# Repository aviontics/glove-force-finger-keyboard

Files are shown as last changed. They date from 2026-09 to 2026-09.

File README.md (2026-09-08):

# Sentient Glove

**A hands-free hotkey glove.** Tap your fingertips to fire keyboard keys on your PC — push-to-talk, Enter, macros, anything — with no Bluetooth pairing, sub-10 ms latency and long range.

Built by [Sentient Robotics](https://sentientrobotics.example) on the ESP32-S3.

---

## How it works

```
 ┌──────────────┐   2.4 GHz ESP-NOW    ┌──────────────┐   USB HID    ┌──────┐
 │  GLOVE       │ ───────────────────▶ │  DONGLE      │ ───────────▶ │  PC  │
 │  ESP32-S3    │   long-range mode    │  ESP32-S3    │  (keyboard)  │      │
 │  3 × FSR     │                      │              │ ◀──────────▶ │      │
 └──────────────┘                      └──────────────┘  USB serial  └──────┘
                                                          (config app)
```

- The **glove** carries an ESP32-S3 and three thin-film force sensors on the fingertips. It detects taps, double-taps and long presses and sends them by radio.
- The **dongle** is a second ESP32-S3 plugged into the PC. It appears as a standard wired USB keyboard and turns each gesture into a keystroke. The key mapping lives on the dongle in flash, so remapping never touches the glove.
- The **Sentient Glove Control** desktop app talks to the dongle over USB serial to configure key mappings and show live telemetry, including a range radar.

Because the dongle is a plain USB keyboard, it works on any machine with no drivers and no pairing.

---

## Repository layout

| Path | What it is |
|---|---|
| `firmware/glove_sender_v2.ino` | Glove firmware: sensor reading, gesture engine, heartbeat, LED |
| `firmware/dongle_hid_v4.ino` | Dongle firmware: ESP-NOW receiver, USB HID keyboard, keymap storage, serial protocol |
| `app/sentient_glove_control.py` | PyQt6 desktop configurator |
| `hardware/` | Enclosure CAD (Fusion 360) and bill of materials |

---

## Hardware

### Bill of materials (per glove)

| Qty | Part | Notes |
|---|---|---|
| 1 | Seeed XIAO ESP32S3 Plus | Glove controller. Built-in LiPo charging. |
| 1 | ESP32-S3 board with native USB (XIAO ESP32S3 or S3 mini dev board) | Dongle |
| 3 | Thin-film force-sensitive resistor (FSR 400 type, 20 g–10 kg) | One per fingertip |
| 1 | 3.7 V LiPo, ~500 mAh, JST-PH | Glove power |
| 1 | Mini slide switch | Battery on/off |
| 1 | Thin sports/cycling glove | Wearable base |
| — | 30 AWG silicone wire, heat-shrink, adhesive | Harness |
| — | 3D-printed enclosure (see `hardware/`) | Two-tier case: battery below, board above |

No resistors are required: the sensors are read in **digital mode** using the ESP32's internal pull-ups.

### Wiring the glove

Each sensor connects between **its GPIO and GND**. Nothing connects to 3V3.

| Finger | GPIO | XIAO pin |
|---|---|---|
| 1 | GPIO1 | A0 / D0 |
| 2 | GPIO5 | D4 |
| 3 | GPIO3 | A2 / D2 |

Both GND legs from all three sensors can share one wire back to the board's GND pin.

> **Handling FSRs:** never solder directly to the sensor's film tail — the printed traces delaminate with heat. Use crimp connectors or a slide-on female header.

> **GPIO3 is a strapping pin.** Don't hold finger 3 pressed while powering on or resetting the glove.

Battery: solder the LiPo to the BAT+ / BAT− pads on the underside of the XIAO, with the slide switch in the BAT+ line. Charging happens automatically over the board's USB-C.

### Power-on indicator

The XIAO's user LED (GPIO21) flashes briefly every two seconds while the glove is running. Flip the switch on → LED flashes; off → dark. The orange LED next to it is the charger and lights on its own while charging.

---

## Firmware

Both boards are programmed from the Arduino IDE with the **esp32** board package (3.x) installed via Boards Manager. Use **Arduino IDE 2.x** — on Ubuntu, install it from arduino.cc, not the snap, and add yourself to the `dialout` group.

### Glove — `glove_sender_v2.ino`

Board: your XIAO ESP32S3 / ESP32S3 Dev Module. Default USB settings. Flash normally.

Adding sensors later is a two-line edit at the top of the file:

```cpp
const uint8_t NUM = 3;
const uint8_t fsrPins[NUM]     = {1, 5, 3};
const bool    dtapEnabled[NUM] = {true, true, true};
```

### Dongle — `dongle_hid_v4.ino`

Board settings that matter:

| Setting | Value |
|---|---|
| USB Mode | **USB-OTG (TinyUSB)** |
| USB CDC On Boot | **Enabled** |

**Flashing a board that is already running dongle firmware:** the auto-reset doesn't work in OTG mode, so:

1. Hold **BOOT**, tap **RESET**, release **BOOT** — the board enters download mode and its serial port appears.
2. Upload.
3. Press **RESET** once more to run the new firmware. (Forgetting this leaves the board sitting in the bootloader: no keyboard, and a serial port that never answers.)

After flashing, the dongle shows up as a USB keyboard *and* a USB serial port at the same time.

Both boards are hard-coded to radio channel 6 in long-range mode and must match. They pair automatically — no MAC addresses to enter.

---

## Using the glove

### Gestures

Every finger supports three independent gestures. Each is mapped to a **binding**: any combination of Ctrl / Shift / Alt / Win plus one key.

| Gesture | How | Default bindings (F1 / F2 / F3) |
|---|---|---|
| **Tap** | Press and release within 400 ms | `a` / `Ctrl+Alt+J` / `Enter` |
| **Double tap** | Two taps within 250 ms | `A` / `B` / `C` |
| **Long press** | Hold longer than 400 ms | `Ctrl+Alt+R` / `F14` / `F15` |

Long press behaves like holding real keys: the whole combination goes **down** at the 400 ms mark and comes **up** when you let go. This is how push-to-talk works — e.g. finger 1 long press = `Ctrl+Alt+R` held for as long as the finger is down. Modifiers are reference-counted on the dongle, so tapping another finger's combo while a PTT combo is held never releases the shared modifiers.

F13–F24 are the recommended PTT keys: no application uses them by default, so they never collide with anything. Bind them in Discord, TeamSpeak or your game.

**Latency note:** on a finger with double-tap enabled, a single tap fires ~250 ms after release (the glove waits to see if a second tap is coming). Fingers with double-tap disabled fire instantly. Set `dtapEnabled` per finger accordingly.

### Setup mode (remap without the app)

Hold any sensor for **10 seconds**. The glove requests setup for that finger; if the desktop app is connected, a dialog opens to assign its three keys. Release the sensor, choose the keys, done. Mappings are saved to the dongle's flash immediately and survive power cycles.

> During the 10-second hold the long-press key is held down until the 10 s mark, then released. Click into the app or a harmless window first.

Timing constants (`LONG_MS`, `DOUBLE_GAP_MS`, `SETUP_MS`) are at the top of the glove firmware if you want to tune the feel.

---

## Sentient Glove Control (desktop app)

Sentient Glove Control

### Install

```bash
pip install PyQt6 pyserial
python app/sentient_glove_control.py
```

Runs on Windows, macOS and Linux. On Linux you need read/write access to the dongle's serial port (`dialout` group on Ubuntu).

### Interface

**Dongle Link** — click **SCAN**, choose the dongle's port, click **CONNECT**. The status indicator turns green (`GLOVE ONLINE`) as soon as heartbeats arrive from the glove. `SERIAL ONLY — NO GLOVE` means the dongle is connected but the glove is off or out of range.

**Key Mapping** — a grid of finger × gesture. Each cell is a key picker with **Ctrl / Shift / Alt / Win** tickboxes beneath it: choose a named key from the dropdown (Enter, Backspace, Tab, Esc, Space, Delete, Home/End, Page Up/Down, arrows, F1–F24) or type a single character, then tick the modifiers you want combined with it. Leave the key blank to unassign that gesture (or blank with modifiers ticked for a modifier-only binding).
- **READ FROM DEVICE** pulls the current map from the dongle.
- **APPLY ALL** writes every cell to the dongle's flash.

**Telemetry** — live log of every gesture received (`finger 2: DOUBLE TAP`), setup requests and command results. Use it to verify sensors and timing.

**Glove Range** — a sweep radar showing link strength (RSSI). The blip drifts outward as signal weakens; the centre shows an estimated distance. Click **CALIBRATE @ 1 m** with the glove one metre from the dongle to anchor the estimate to your hardware. Distance derived from signal strength is indicative only — it's a link-health indicator, not a tape measure. `NO LINK` appears if no heartbeat arrives for 2 seconds.

### Serial protocol

The app is optional — anything that speaks 115200-baud serial can configure the dongle.

| Direction | Message | Meaning |
|---|---|---|
| PC → dongle | `GET` | Request the keymap |
| PC → dongle | `SET,f,slot,mods,code` | Set finger `f` (0–5), slot `t`/`d`/`l` (tap/double/long): `mods` bitmask (1 Ctrl, 2 Shift, 4 Alt, 8 Win) + HID keycode `code` (0–255; 0 = none) |
| dongle → PC | `READY` | Booted |
| dongle → PC | `MAP,f,tm,tk,dm,dk,lm,lk` | One line per finger: mods,key for tap, double-tap, long press |
| dongle → PC | `EV,f,code` | Gesture received: 1 tap, 2 double, 3 long start, 4 long end, 5 setup |
| dongle → PC | `HB,rssi` | Heartbeat with link RSSI in dBm (every ~400 ms) |
| dongle → PC | `SETUP,f` | Glove requested setup for finger `f` |
| dongle → PC | `OK` / `ERR` | Command result |

Keycodes follow the Arduino keyboard convention: printable characters are their ASCII value; special keys are `0x80`+ (Enter `176`, Backspace `178`, F13 `240`, …).

---

## Troubleshooting

| Symptom | Likely cause | Fix |
|---|---|---|
| Nothing types, app opens the port but gets no response | Dongle stuck in bootloader after flashing | Press **RESET** on the dongle |
| Serial port disappears after flashing the dongle | Expected — it's now a keyboard | Enable *USB CDC On Boot*, and use BOOT+RESET to reflash |
| App connects but `NO LINK` | Glove off, out of range, or channel/LR mismatch | Check switch/LED, bring closer, confirm both firmwares use channel 6 + LR |
| A tap fires on two fingers at once | Sensor wires bridged or wrong pins | Continuity-check between finger signal wires; verify GPIO assignments |
| Taps trigger too easily / when gripping things | Thin-film sensors are sensitive | Raise `DEBOUNCE_MS`, mount sensors flat (not under tension), or use firmer press |
| Slow single taps | Double-tap wait | Set `dtapEnabled` to `false` for that finger |
| Glove won't reset/boot | Finger 3 held during power-up | Release finger 3 (GPIO3 is a strapping pin) |

---

## Roadmap

- Battery percentage reported to the app (spare byte in the heartbeat)
- Multi-key macros / sequences per gesture
- Media keys (volume, play/pause)
- Per-finger settings in the app (double-tap enable, timing)

---

## License

MIT — see `LICENSE`.

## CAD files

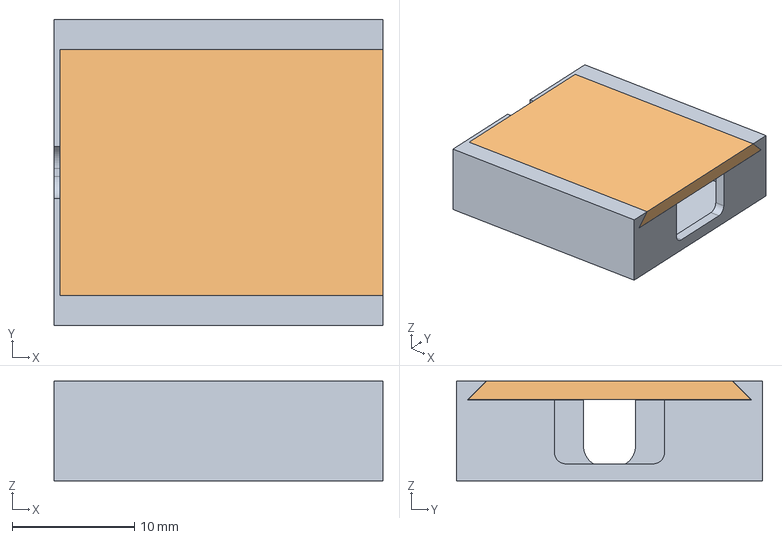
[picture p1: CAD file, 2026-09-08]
hardware/glovecase-dongle-case.step
26.9 x 25.0 x 8.14 mm

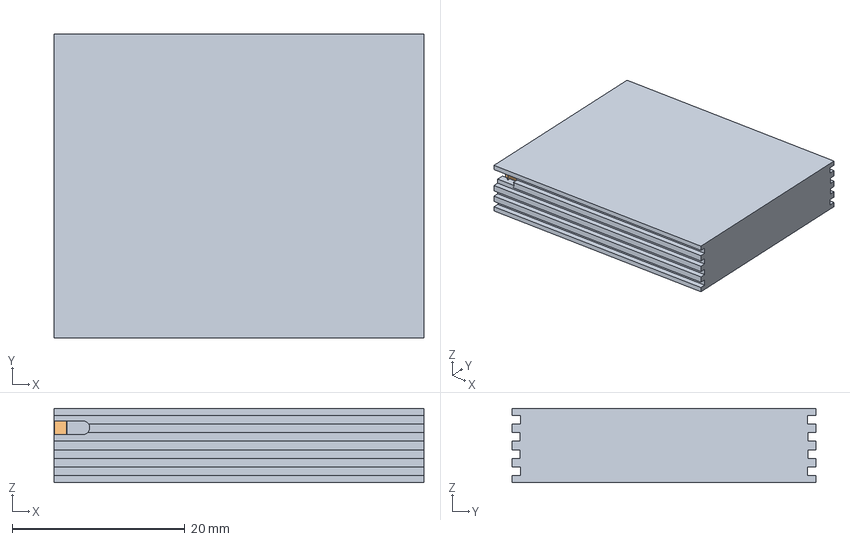
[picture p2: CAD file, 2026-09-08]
hardware/glovecase-battery-case.step
42.9 x 35.3 x 8.59 mm

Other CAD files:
hardware/glovecase-donlge-case-and-battery-case.f3d

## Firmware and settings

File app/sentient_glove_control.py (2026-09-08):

#!/usr/bin/env python3
"""
SENTIENT GLOVE CONTROL
Desktop configurator for the Sentient Robotics hands-free hotkey glove.

Requires:  pip install PyQt6 pyserial
Firmware:  dongle_hid_v2.ino on the dongle, glove_sender_v2.ino on the glove.
Run:       python sentient_glove_control.py
"""

import math
import sys
import time

import serial
from serial.tools import list_ports
from PyQt6 import QtCore, QtGui, QtWidgets

FINGERS = 3          # rows shown in the mapper (firmware supports up to 6)
BAUD = 115200
EV_NAMES = {1: "TAP", 2: "DOUBLE TAP", 3: "LONG PRESS \u25bc", 4: "LONG PRESS \u25b2", 5: "SETUP REQUEST"}
SLOTS = [("t", "Tap"), ("d", "Double tap"), ("l", "Long press")]

# HID keycodes as used by the ESP32 USBHIDKeyboard library (Arduino Keyboard convention).
# Printable keys are their ASCII value; specials live at 0x80+. 0 = unassigned.
SPECIAL_KEYS = [
    ("Enter", 0xB0), ("Backspace", 0xB2), ("Tab", 0xB3), ("Esc", 0xB1), ("Space", 0x20),
    ("Delete", 0xD4), ("Insert", 0xD1), ("Home", 0xD2), ("End", 0xD5),
    ("Page Up", 0xD3), ("Page Down", 0xD6),
    ("Up", 0xDA), ("Down", 0xD9), ("Left", 0xD8), ("Right", 0xD7),
    ("Left Ctrl", 0x80), ("Left Shift", 0x81), ("Left Alt", 0x82), ("Left GUI/Win", 0x83),
    ("Right Ctrl", 0x84), ("Right Shift", 0x85), ("Right Alt", 0x86), ("Right GUI/Win", 0x87),
    ("Caps Lock", 0xC1), ("Print Screen", 0xCE), ("Scroll Lock", 0xCF), ("Pause", 0xD0),
] + [(f"F{n}", 0xC2 + n - 1) for n in range(1, 13)] \
  + [(f"F{n}", 0xF0 + n - 13) for n in range(13, 25)]
NAME_TO_CODE = {name.lower(): code for name, code in SPECIAL_KEYS}
CODE_TO_NAME = {code: name for name, code in SPECIAL_KEYS}


def code_to_label(code: int) -> str:
    if code == 0:
        return ""
    if code in CODE_TO_NAME:
        return CODE_TO_NAME[code]
    if 33 <= code <= 126:
        return chr(code)
    return f"#{code}"


def label_to_code(text: str):
    """Returns a keycode, 0 for blank/none, or None if unrecognised."""
    t = text.strip()
    if t == "" or t.lower() in ("none", "-", "--"):
        return 0
    if t.lower() in NAME_TO_CODE:
        return NAME_TO_CODE[t.lower()]
    if len(t) == 1 and 33 <= ord(t) <= 126:
        return ord(t)
    if t.startswith("#") and t[1:].isdigit() and 0 <= int(t[1:]) <= 255:
        return int(t[1:])
    return None


class KeyPicker(QtWidgets.QComboBox):
    """Editable combo: pick a named special key, or type a single character."""

    def __init__(self):
        super().__init__()
        self.setEditable(True)
        self.setInsertPolicy(QtWidgets.QComboBox.InsertPolicy.NoInsert)
        self.addItem("")
        for name, _ in SPECIAL_KEYS:
            self.addItem(name)
        self.setFixedWidth(112)
        self.lineEdit().setObjectName("keycap")
        self.setToolTip("Type one character, or choose a special key")

    def set_code(self, code: int):
        self.setCurrentText(code_to_label(code))

    def code(self):
        return label_to_code(self.currentText())


MODS = [("Ctrl", 1), ("Shift", 2), ("Alt", 4), ("Win", 8)]


class KeyCell(QtWidgets.QWidget):
    """One gesture binding: modifier tickboxes + key picker."""

    def __init__(self):
        super().__init__()
        lay = QtWidgets.QVBoxLayout(self)
        lay.setContentsMargins(0, 0, 0, 0)
        lay.setSpacing(3)
        self.picker = KeyPicker()
        lay.addWidget(self.picker, 0, QtCore.Qt.AlignmentFlag.AlignHCenter)
        row = QtWidgets.QHBoxLayout()
        row.setSpacing(6)
        self.boxes = {}
        for name, bit in MODS:
            cb = QtWidgets.QCheckBox(name)
            self.boxes[bit] = cb
            row.addWidget(cb)
        lay.addLayout(row)

    def set_binding(self, mods: int, code: int):
        self.picker.set_code(code)
        for bit, cb in self.boxes.items():
            cb.setChecked(bool(mods & bit))

    def binding(self):
        """(mods, code) or None if the key text is unrecognised."""
        code = self.picker.code()
        if code is None:
            return None
        mods = sum(bit for bit, cb in self.boxes.items() if cb.isChecked())
        return mods, code

ACCENT = "#00e5ff"
ACCENT2 = "#1de9b6"
WARN = "#ff5370"
BG = "#070c11"
PANEL = "#0d151d"
TEXT = "#cfe8e6"

QSS = f"""
* {{ font-family: 'Segoe UI', 'DejaVu Sans', sans-serif; }}
QMainWindow, QDialog {{ background: {BG}; }}
QWidget {{ color: {TEXT}; font-size: 13px; }}
QGroupBox {{
    background: {PANEL};
    border: 1px solid #16323d;
    border-radius: 10px;
    margin-top: 14px;
    padding: 10px 8px 8px 8px;
}}
QGroupBox::title {{
    subcontrol-origin: margin; left: 14px; padding: 0 6px;
    color: {ACCENT}; letter-spacing: 3px; font-size: 11px; font-weight: 600;
}}
QPushButton {{
    background: #0f2530; color: {ACCENT};
    border: 1px solid #1a4a5a; border-radius: 6px;
    padding: 6px 14px; letter-spacing: 1px;
}}
QPushButton:hover {{ background: #143544; border-color: {ACCENT}; }}
QPushButton:pressed {{ background: #0a1c26; }}
QPushButton:disabled {{ color: #3a5560; border-color: #14303a; }}
QPushButton#danger {{ color: {WARN}; border-color: #5a1a2a; }}
QComboBox, QLineEdit {{
    background: #091018; border: 1px solid #1a4a5a; border-radius: 6px;
    padding: 5px 8px; color: {TEXT}; selection-background-color: #145a6e;
}}
QLineEdit:focus, QComboBox:focus {{ border-color: {ACCENT}; }}
QLineEdit#keycap {{
    font-family: 'Consolas', 'DejaVu Sans Mono', monospace;
    font-size: 14px; font-weight: 700; color: {ACCENT2};
    qproperty-alignment: AlignCenter;
    border: none; background: transparent;
}}
QCheckBox {{ color: #6f9aa6; font-size: 10px; letter-spacing: 1px; spacing: 3px; }}
QCheckBox::indicator {{
    width: 11px; height: 11px; border: 1px solid #1a4a5a; border-radius: 3px; background: #091018;
}}
QCheckBox::indicator:checked {{ background: {ACCENT}; border-color: {ACCENT}; }}
QComboBox QAbstractItemView {{
    background: #091018; color: {TEXT}; selection-background-color: #145a6e;
    border: 1px solid #1a4a5a;
}}
QPlainTextEdit {{
    background: #050a0f; border: 1px solid #16323d; border-radius: 8px;
    font-family: 'Consolas', 'DejaVu Sans Mono', monospace; font-size: 12px;
    color: #8fd8c8;
}}
QLabel#title {{
    color: {ACCENT}; font-size: 22px; font-weight: 300; letter-spacing: 8px;
}}
QLabel#subtitle {{ color: #4d7a86; font-size: 10px; letter-spacing: 4px; }}
QLabel#status_ok {{ color: {ACCENT2}; letter-spacing: 2px; }}
QLabel#status_bad {{ color: {WARN}; letter-spacing: 2px; }}
QLabel#colhead {{ color: #4d7a86; font-size: 10px; letter-spacing: 2px; }}
"""


# ----------------------------------------------------------------------
class SerialWorker(QtCore.QThread):
    """Owns the serial port; emits every incoming line."""
    line = QtCore.pyqtSignal(str)
    closed = QtCore.pyqtSignal(str)

    def __init__(self, port: str):
        super().__init__()
        self._port_name = port
        self._ser = None
        self._run = True
        self._lock = QtCore.QMutex()

    def run(self):
        try:
            self._ser = serial.Serial(self._port_name, BAUD, timeout=0.2)
        except Exception as e:                                    # noqa: BLE001
            self.closed.emit(f"open failed: {e}")
            return
        buf = b""
        while self._run:
            try:
                chunk = self._ser.read(64)
            except Exception as e:                                # noqa: BLE001
                self.closed.emit(f"link lost: {e}")
                break
            if chunk:
                buf += chunk
                while b"\n" in buf:
                    raw, buf = buf.split(b"\n", 1)
                    text = raw.decode(errors="replace").strip()
                    if text:
                        self.line.emit(text)
        try:
            if self._ser and self._ser.is_open:
                self._ser.close()
        except Exception:                                         # noqa: BLE001
            pass

    def send(self, text: str):
        with QtCore.QMutexLocker(self._lock):
            if self._ser and self._ser.is_open:
                try:
                    self._ser.write((text + "\n").encode())
                except Exception:                                 # noqa: BLE001
                    pass

    def stop(self):
        self._run = False
        self.wait(1000)


# ----------------------------------------------------------------------
class RangeRadar(QtWidgets.QWidget):
    """Futuristic sweep radar showing link RSSI and an estimated range."""

    def __init__(self):
        super().__init__()
        self.setMinimumSize(260, 260)
        self.rssi = None          # smoothed dBm
        self.linked = False
        self.dist = None          # metres, estimated
        self._sweep = 0.0
        timer = QtCore.QTimer(self)
        timer.timeout.connect(self._tick)
        timer.start(33)

    def _tick(self):
        self._sweep = (self._sweep + 2.4) % 360.0
        self.update()

    def set_link(self, rssi, dist, linked):
        self.rssi, self.dist, self.linked = rssi, dist, linked

    def paintEvent(self, _ev):
        p = QtGui.QPainter(self)
        p.setRenderHint(QtGui.QPainter.RenderHint.Antialiasing)
        w, h = self.width(), self.height()
        cx, cy = w / 2, h / 2
        r = min(w, h) / 2 - 12

        p.fillRect(self.rect(), QtGui.QColor(BG))

        grid = QtGui.QPen(QtGui.QColor(20, 60, 72), 1)
        p.setPen(grid)
        for frac in (1.0, 0.72, 0.45, 0.2):
            p.drawEllipse(QtCore.QPointF(cx, cy), r * frac, r * frac)
        p.drawLine(QtCore.QPointF(cx - r, cy), QtCore.QPointF(cx + r, cy))
        p.drawLine(QtCore.QPointF(cx, cy - r), QtCore.QPointF(cx, cy + r))

        if self.linked:
            # sweep wedge
            grad = QtGui.QConicalGradient(cx, cy, -self._sweep)
            grad.setColorAt(0.0, QtGui.QColor(0, 229, 255, 120))
            grad.setColorAt(0.12, QtGui.QColor(0, 229, 255, 0))
            grad.setColorAt(1.0, QtGui.QColor(0, 229, 255, 0))
            p.setBrush(QtGui.QBrush(grad))
            p.setPen(QtCore.Qt.PenStyle.NoPen)
            p.drawEllipse(QtCore.QPointF(cx, cy), r, r)

            # strength arc: map RSSI -95..-30 dBm -> 0..1
            if self.rssi is not None:
                pct = max(0.0, min(1.0, (self.rssi + 95.0) / 65.0))
                pen = QtGui.QPen(QtGui.QColor(ACCENT2), 5)
                pen.setCapStyle(QtCore.Qt.PenCapStyle.RoundCap)
                p.setPen(pen)
                rect = QtCore.QRectF(cx - r + 4, cy - r + 4, 2 * r - 8, 2 * r - 8)
                p.drawArc(rect, 90 * 16, -int(360 * 16 * pct))

            # glove blip at radius proportional to (1 - strength)
            if self.rssi is not None:
                pct = max(0.0, min(1.0, (self.rssi + 95.0) / 65.0))
                blip_r = r * (0.15 + 0.75 * (1.0 - pct))
                ang = math.radians(self._sweep)
                bx = cx + blip_r * math.cos(ang)
                by = cy - blip_r * math.sin(ang)
                p.setPen(QtCore.Qt.PenStyle.NoPen)
                p.setBrush(QtGui.QColor(ACCENT))
                p.drawEllipse(QtCore.QPointF(bx, by), 4, 4)

        # centre text
        p.setPen(QtGui.QColor(ACCENT if self.linked else WARN))
        f = p.font()
        f.setPointSize(17)
        f.setLetterSpacing(QtGui.QFont.SpacingType.AbsoluteSpacing, 1.5)
        p.setFont(f)
        if not self.linked:
            centre = "NO LINK"
        elif self.dist is None:
            centre = "--"
        else:
            centre = f"\u2248 {self.dist:.1f} m"
        p.drawText(self.rect().adjusted(0, -10, 0, -10),
                   QtCore.Qt.AlignmentFlag.AlignCenter, centre)

        f.setPointSize(9)
        p.setFont(f)
        p.setPen(QtGui.QColor("#4d7a86"))
        sub = f"RSSI {self.rssi:.0f} dBm" if (self.linked and self.rssi is not None) else "awaiting heartbeat"
        p.drawText(self.rect().adjusted(0, 34, 0, 0),
                   QtCore.Qt.AlignmentFlag.AlignCenter, sub)
        p.end()


# ----------------------------------------------------------------------
class SetupDialog(QtWidgets.QDialog):
    """Shown when the glove requests setup (10 s hold on a sensor)."""

    def __init__(self, finger: int, current: dict, parent=None):
        super().__init__(parent)
        self.setWindowTitle(f"Configure finger {finger + 1}")
        self.setStyleSheet(QSS)
        lay = QtWidgets.QFormLayout(self)
        head = QtWidgets.QLabel(f"SETUP MODE \u2014 FINGER {finger + 1}")
        head.setObjectName("status_ok")
        lay.addRow(head)
        self.edits = {}
        for slot, label in SLOTS:
            e = KeyCell()
            m, c = current.get(slot, (0, 0))
            e.set_binding(m, c)
            self.edits[slot] = e
            lay.addRow(label, e)
        bb = QtWidgets.QDialogButtonBox(
            QtWidgets.QDialogButtonBox.StandardButton.Ok
            | QtWidgets.QDialogButtonBox.StandardButton.Cancel)
        bb.accepted.connect(self.accept)
        bb.rejected.connect(self.reject)
        lay.addRow(bb)

    def values(self):
        out = {}
        for slot, e in self.edits.items():
            b = e.binding()
            if b is not None:
                out[slot] = b
        return out


# ----------------------------------------------------------------------
class MainWindow(QtWidgets.QMainWindow):
    def __init__(self):
        super().__init__()
        self.setWindowTitle("Sentient Glove Control")
        self.resize(1120, 680)
        self.setStyleSheet(QSS)

        self.worker = None
        self.rssi_ema = None
        self.rssi_at_1m = -50.0       # calibratable
        self.path_exp = 2.4
        self.last_hb = 0.0

        central = QtWidgets.QWidget()
        self.setCentralWidget(central)
        root = QtWidgets.QVBoxLayout(central)
        root.setContentsMargins(18, 14, 18, 14)

        # ---------- header ----------
        head = QtWidgets.QHBoxLayout()
        tcol = QtWidgets.QVBoxLayout()
        title = QtWidgets.QLabel("SENTIENT GLOVE CONTROL")
        title.setObjectName("title")
        sub = QtWidgets.QLabel("SENTIENT ROBOTICS \u2022 HANDS-FREE HOTKEY SYSTEM")
        sub.setObjectName("subtitle")
        tcol.addWidget(title)
        tcol.addWidget(sub)
        head.addLayout(tcol)
        head.addStretch(1)
        self.status = QtWidgets.QLabel("\u25cf OFFLINE")
        self.status.setObjectName("status_bad")
        head.addWidget(self.status)
        root.addLayout(head)

        body = QtWidgets.QHBoxLayout()
        root.addLayout(body, 1)
        left = QtWidgets.QVBoxLayout()
        right = QtWidgets.QVBoxLayout()
        body.addLayout(left, 3)
        body.addLayout(right, 2)

        # ---------- connection ----------
        conn = QtWidgets.QGroupBox("DONGLE LINK")
        cl = QtWidgets.QHBoxLayout(conn)
        self.port_box = QtWidgets.QComboBox()
        self.btn_refresh = QtWidgets.QPushButton("SCAN")
        self.btn_conn = QtWidgets.QPushButton("CONNECT")
        cl.addWidget(self.port_box, 1)
        cl.addWidget(self.btn_refresh)
        cl.addWidget(self.btn_conn)
        left.addWidget(conn)

        # ---------- keymap ----------
        km = QtWidgets.QGroupBox("KEY MAPPING")
        grid = QtWidgets.QGridLayout(km)
        grid.setHorizontalSpacing(14)
        for col, name in enumerate(["FINGER", "TAP", "DOUBLE TAP", "LONG PRESS"]):
            lbl = QtWidgets.QLabel(name)
            lbl.setObjectName("colhead")
            grid.addWidget(lbl, 0, col, QtCore.Qt.AlignmentFlag.AlignHCenter)
        self.key_edits = []           # [finger][slot] -> QLineEdit
        for f in range(FINGERS):
            grid.addWidget(QtWidgets.QLabel(f"F{f + 1}"), f + 1, 0,
                           QtCore.Qt.AlignmentFlag.AlignHCenter)
            row = {}
            for col, (slot, _label) in enumerate(SLOTS, start=1):
                e = KeyCell()
                grid.addWidget(e, f + 1, col, QtCore.Qt.AlignmentFlag.AlignHCenter)
                row[slot] = e
            self.key_edits.append(row)
        btns = QtWidgets.QHBoxLayout()
        self.btn_read = QtWidgets.QPushButton("READ FROM DEVICE")
        self.btn_apply = QtWidgets.QPushButton("APPLY ALL")
        btns.addWidget(self.btn_read)
        btns.addWidget(self.btn_apply)
        btns.addStretch(1)
        grid.addLayout(btns, FINGERS + 1, 0, 1, 4)
        left.addWidget(km)

        # ---------- event log ----------
        lg = QtWidgets.QGroupBox("TELEMETRY")
        ll = QtWidgets.QVBoxLayout(lg)
        self.log = QtWidgets.QPlainTextEdit()
        self.log.setReadOnly(True)
        self.log.setMaximumBlockCount(500)
        ll.addWidget(self.log)
        left.addWidget(lg, 1)

        # ---------- radar ----------
        rg = QtWidgets.QGroupBox("GLOVE RANGE  (RSSI ESTIMATE)")
        rl = QtWidgets.QVBoxLayout(rg)
        self.radar = RangeRadar()
        rl.addWidget(self.radar, 1)
        cal = QtWidgets.QHBoxLayout()
        self.btn_cal = QtWidgets.QPushButton("CALIBRATE @ 1 m")
        self.cal_lbl = QtWidgets.QLabel("ref \u2212 50 dBm")
        self.cal_lbl.setObjectName("colhead")
        cal.addWidget(self.btn_cal)
        cal.addWidget(self.cal_lbl)
        cal.addStretch(1)
        rl.addLayout(cal)
        note = QtWidgets.QLabel("Range is inferred from signal strength \u2014 indicative only.")
        note.setObjectName("colhead")
        note.setWordWrap(True)
        rl.addWidget(note)
        right.addWidget(rg, 1)

        # ---------- wiring ----------
        self.btn_refresh.clicked.connect(self.scan_ports)
        self.btn_conn.clicked.connect(self.toggle_conn)
        self.btn_read.clicked.connect(lambda: self._send("GET"))
        self.btn_apply.clicked.connect(self.apply_all)
        self.btn_cal.clicked.connect(self.calibrate)

        self.watchdog = QtCore.QTimer(self)
        self.watchdog.timeout.connect(self._check_link)
        self.watchdog.start(500)

        self.scan_ports()
        self._set_online(False)

    # ---------------- serial plumbing ----------------
    def scan_ports(self):
        self.port_box.clear()
        for p in list_ports.comports():
            self.port_box.addItem(f"{p.device}  \u2014  {p.description}", p.device)

    def toggle_conn(self):
        if self.worker:
            self.worker.stop()
            self.worker = None
            self._set_online(False)
            self._log("link closed")
            self.btn_conn.setText("CONNECT")
            return
        if self.port_box.currentIndex() < 0:
            self._log("no port selected")
            return
        port = self.port_box.currentData()
        self.worker = SerialWorker(port)
        self.worker.line.connect(self.on_line)
        self.worker.closed.connect(self.on_closed)
        self.worker.start()
        self.btn_conn.setText("DISCONNECT")
        self._log(f"opening {port} \u2026")
        QtCore.QTimer.singleShot(800, lambda: self._send("GET"))

    def on_closed(self, why: str):
        self._log(why)
        self.worker = None
        self.btn_conn.setText("CONNECT")
        self._set_online(False)

    def _send(self, text: str):
        if self.worker:
            self.worker.send(text)

    # ---------------- protocol ----------------
    def on_line(self, s: str):
        self.last_hb_seen = True
        if s.startswith("HB,"):
            try:
                r = float(s[3:])
            except ValueError:
                return
            self.last_hb = time.monotonic()
            self.rssi_ema = r if self.rssi_ema is None else (0.8 * self.rssi_ema + 0.2 * r)
            d = 10 ** ((self.rssi_at_1m - self.rssi_ema) / (10 * self.path_exp))
            d = max(0.1, min(300.0, d))
            self.radar.set_link(self.rssi_ema, d, True)
            self._set_online(True)
            return
        if s.startswith("MAP,"):
            parts = s.split(",")
            if len(parts) == 8 and all(p.isdigit() for p in parts[1:]):
                f = int(parts[1])
                if 0 <= f < FINGERS:
                    vals = [int(p) for p in parts[2:8]]
                    for i, (slot, _) in enumerate(SLOTS):
                        self.key_edits[f][slot].set_binding(vals[2 * i], vals[2 * i + 1])
            return
        if s.startswith("EV,"):
            parts = s.split(",")
            if len(parts) == 3:
                name = EV_NAMES.get(int(parts[2]) if parts[2].isdigit() else 0, "?")
                self._log(f"finger {int(parts[1]) + 1}: {name}")
            return
        if s.startswith("SETUP,"):
            try:
                f = int(s.split(",")[1])
            except (ValueError, IndexError):
                return
            self._log(f"finger {f + 1}: SETUP MODE requested")
            if f < FINGERS:
                self.run_setup(f)
            return
        if s in ("READY", "OK", "ERR"):
            self._log(s.lower())
            return
        self._log(s)

    def run_setup(self, f: int):
        current = {slot: (self.key_edits[f][slot].binding() or (0, 0)) for slot, _ in SLOTS}
        dlg = SetupDialog(f, current, self)
        if dlg.exec():
            for slot, (mods, code) in dlg.values().items():
                self._send(f"SET,{f},{slot},{mods},{code}")
                self.key_edits[f][slot].set_binding(mods, code)
            self._log(f"finger {f + 1}: mapping saved")

    def apply_all(self):
        if not self.worker:
            self._log("not connected")
            return
        n, bad = 0, []
        for f in range(FINGERS):
            for slot, _ in SLOTS:
                b = self.key_edits[f][slot].binding()
                if b is None:
                    bad.append(f"F{f + 1} {dict(SLOTS)[slot].lower()}")
                    continue
                mods, code = b
                self._send(f"SET,{f},{slot},{mods},{code}")
                n += 1
        self._log(f"sent {n} mapping(s)" + (f"; unrecognised: {', '.join(bad)}" if bad else ""))
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

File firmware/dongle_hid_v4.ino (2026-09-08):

// ============================================================
// SENTIENT GLOVE - DONGLE v4  (USB receiver side)
// Board: ESP32-S3. Tools -> USB Mode: "USB-OTG (TinyUSB)",
//                  USB CDC On Boot: Enabled
//
// Each gesture slot is a BINDING: modifier set + key.
//   mods bitmask: bit0 Ctrl, bit1 Shift, bit2 Alt, bit3 Win/GUI
//   code: HID keycode (ASCII for printable, KEY_* for specials, 0 = none)
// Long press = binding held down until the finger releases (true PTT).
// Modifiers are reference-counted so a tap on one finger never
// releases a modifier another finger is still holding.
//
// Serial protocol (115200, newline-terminated):
//   PC -> dongle:  GET
//                  SET,f,slot,mods,code      slot t/d/l
//   dongle -> PC:  READY
//                  MAP,f,tm,tk,dm,dk,lm,lk   per finger: mods,key for tap/double/long
//                  EV,f,code                 1 tap 2 dtap 3 long-start 4 long-end 5 setup
//                  HB,rssi
//                  SETUP,f
//                  OK / ERR
// ============================================================
#include <WiFi.h>
#include <esp_now.h>
#include <esp_wifi.h>
#include "USB.h"
#include "USBHIDKeyboard.h"
#include <Preferences.h>

USBHIDKeyboard Keyboard;
Preferences prefs;

const uint8_t MAX_F = 6;
enum EvCode : uint8_t { EV_TAP = 1, EV_DTAP, EV_LONG_START, EV_LONG_END, EV_SETUP };
const uint8_t HB_FINGER = 0xFF;
struct TapEvent { uint8_t finger; uint8_t event; };

enum { MOD_CTRL = 1, MOD_SHIFT = 2, MOD_ALT = 4, MOD_GUI = 8 };
const uint8_t modKey[4] = {KEY_LEFT_CTRL, KEY_LEFT_SHIFT, KEY_LEFT_ALT, KEY_LEFT_GUI};
uint8_t modCount[4] = {0, 0, 0, 0};

struct KeyBind { uint8_t mods; uint8_t code; };
KeyBind bind[MAX_F][3];                       // [finger][0 tap, 1 dtap, 2 long]

const KeyBind defBind[MAX_F][3] = {
  {{0, 'a'},                {0, 'A'}, {MOD_CTRL | MOD_ALT, 'r'}},   // F1: long = Ctrl+Alt+R (PTT)
  {{MOD_CTRL | MOD_ALT, 'j'}, {0, 'B'}, {0, KEY_F14}},              // F2: tap = Ctrl+Alt+J
  {{0, KEY_RETURN},         {0, 'C'}, {0, KEY_F15}},                // F3: tap = Enter
  {{0, 'd'},                {0, 'D'}, {0, KEY_F16}},
  {{0, 'e'},                {0, 'E'}, {0, KEY_F17}},
  {{0, 'f'},                {0, 'F'}, {0, KEY_F18}},
};
const char slotChar[3] = {'t', 'd', 'l'};

// ---------- modifier reference counting ----------
void modsDown(uint8_t m) {
  for (int i = 0; i < 4; i++)
    if (m & (1 << i)) { if (modCount[i]++ == 0) Keyboard.press(modKey[i]); }
}
void modsUp(uint8_t m) {
  for (int i = 0; i < 4; i++)
    if (m & (1 << i)) { if (modCount[i] > 0 && --modCount[i] == 0) Keyboard.release(modKey[i]); }
}

void tapBind(const KeyBind& b) {
  if (!b.code && !b.mods) return;
  modsDown(b.mods);
  if (b.code) { Keyboard.press(b.code); delay(8); Keyboard.release(b.code); }
  else        { delay(8); }                   // modifier-only tap
  modsUp(b.mods);
}
void holdBind(const KeyBind& b) {
  modsDown(b.mods);
  if (b.code) Keyboard.press(b.code);
}
void releaseBind(const KeyBind& b) {
  if (b.code) Keyboard.release(b.code);
  modsUp(b.mods);
}

// ---------- radio queue ----------
volatile uint8_t qF[32], qE[32];
volatile int8_t  qR[32];
volatile uint8_t qHead = 0, qTail = 0;

void onRecv(const esp_now_recv_info_t* info, const uint8_t* data, int len) {
  if (len != sizeof(TapEvent)) return;
  TapEvent e;
  memcpy(&e, data, len);
  int8_t rssi = (info && info->rx_ctrl) ? info->rx_ctrl->rssi : 0;
  uint8_t next = (qHead + 1) & 31;
  if (next != qTail) { qF[qHead] = e.finger; qE[qHead] = e.event; qR[qHead] = rssi; qHead = next; }
}

// ---------- persistence ----------
void prefKey(char* k, uint8_t f, uint8_t slot) { k[0] = "TDL"[slot]; k[1] = '0' + f; k[2] = 0; }

void saveBind(uint8_t f, uint8_t slot, KeyBind b) {
  char k[3]; prefKey(k, f, slot);
  prefs.putUShort(k, ((uint16_t)b.mods << 8) | b.code);
  bind[f][slot] = b;
}
void loadBinds() {
  for (uint8_t f = 0; f < MAX_F; f++)
    for (uint8_t s = 0; s < 3; s++) {
      char k[3]; prefKey(k, f, s);
      uint16_t d = ((uint16_t)defBind[f][s].mods << 8) | defBind[f][s].code;
      uint16_t v = prefs.getUShort(k, d);
      bind[f][s] = { (uint8_t)(v >> 8), (uint8_t)(v & 0xFF) };
    }
}

void printMap() {
  for (uint8_t f = 0; f < MAX_F; f++)
    Serial.printf("MAP,%u,%u,%u,%u,%u,%u,%u\n", f,
                  bind[f][0].mods, bind[f][0].code,
                  bind[f][1].mods, bind[f][1].code,
                  bind[f][2].mods, bind[f][2].code);
  Serial.println("OK");
}

// ---------- serial commands ----------
void handleLine(String s) {
  s.trim();
  if (s.length() == 0) return;
  if (s == "GET") { printMap(); return; }
  if (s.startsWith("SET,")) {
    // SET,f,slot,mods,code
    int tok[4]; String rest = s.substring(4); int n = 0; char slot = 0;
    while (n < 4 && rest.length()) {
      int c = rest.indexOf(','); String part = (c < 0) ? rest : rest.substring(0, c);
      if (n == 1) slot = part.charAt(0); else tok[n] = part.toInt();
      rest = (c < 0) ? "" : rest.substring(c + 1); n++;
    }
    int f = tok[0], mods = tok[2], code = tok[3];
    int si = (slot == 't') ? 0 : (slot == 'd') ? 1 : (slot == 'l') ? 2 : -1;
    if (n == 4 && f >= 0 && f < MAX_F && si >= 0 && mods >= 0 && mods <= 15 && code >= 0 && code <= 255) {
      saveBind((uint8_t)f, (uint8_t)si, { (uint8_t)mods, (uint8_t)code });
      Serial.println("OK");
      return;
    }
  }
  Serial.println("ERR");
}

void setup() {
  Serial.begin(115200);
  Keyboard.begin();
  USB.begin();

  WiFi.mode(WIFI_STA);
  esp_wifi_set_channel(6, WIFI_SECOND_CHAN_NONE);
  esp_wifi_set_protocol(WIFI_IF_STA, WIFI_PROTOCOL_LR);
  esp_now_init();
  esp_now_register_recv_cb(onRecv);

  prefs.begin("keymap4");
  loadBinds();
  Serial.println("READY");
  printMap();
}

String rxLine;

void loop() {
  while (Serial.available()) {
    char ch = (char)Serial.read();
    if (ch == '\n' || ch == '\r') { if (rxLine.length()) { handleLine(rxLine); rxLine = ""; } }
    else if (rxLine.length() < 64) rxLine += ch;
  }

  while (qTail != qHead) {
    uint8_t f = qF[qTail], ev = qE[qTail]; int8_t r = qR[qTail];
    qTail = (qTail + 1) & 31;

    if (f == HB_FINGER) { Serial.printf("HB,%d\n", r); continue; }
    if (f >= MAX_F) continue;

    Serial.printf("EV,%u,%u\n", f, ev);
    switch (ev) {
      case EV_TAP:        tapBind(bind[f][0]);     break;
      case EV_DTAP:       tapBind(bind[f][1]);     break;
      case EV_LONG_START: holdBind(bind[f][2]);    break;   // down while finger held
      case EV_LONG_END:   releaseBind(bind[f][2]); break;   // up when finger lifts
      case EV_SETUP:      Serial.printf("SETUP,%u\n", f); break;
    }
  }
}

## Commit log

2026-09-08 First upload of files for the glove finger control
2026-09-08 Glove case for Dongle and Battery. The battery casing
    [glovecase-battery-case.step, glovecase-dongle-case.step, glovecase-donlge-case-and-battery-case.f3d]
